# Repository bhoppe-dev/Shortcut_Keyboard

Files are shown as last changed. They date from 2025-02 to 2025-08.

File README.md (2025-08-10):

# Shortcut Keyboard

A programmable macro keyboard project featuring 8 customizable keys and a rotary encoder for volume control. Built with an RP2040 microcontroller and Cherry MX switches.

<p align="center">
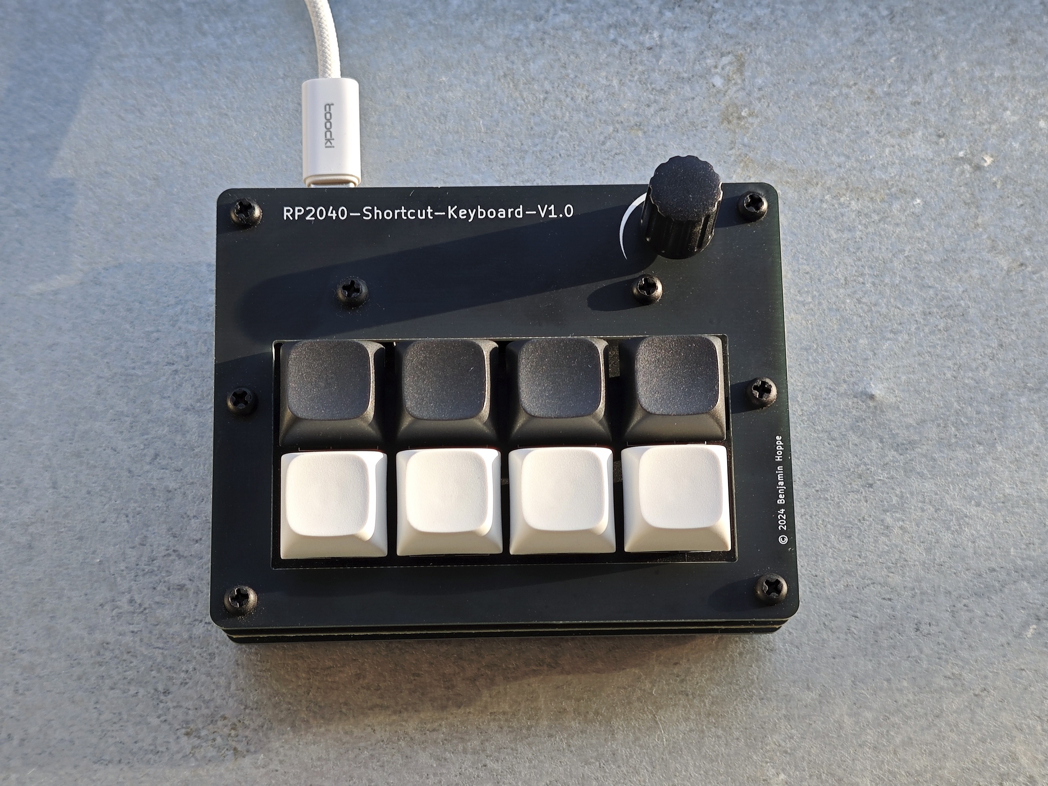
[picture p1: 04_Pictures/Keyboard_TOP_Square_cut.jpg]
  
  <br>
  <em>Shortcut Keyboard PCB</em>
</p>

## Features

- 8 programmable macro keys with Cherry MX switches (Blue or Brown)
- Rotary encoder with push button for volume control/mute
- USB-C connectivity
- RP2040 microcontroller
- CircuitPython firmware
- Windows compatibility
- Up to 3 different profiles for key configurations
- No additional drivers required

## Specifications

| Parameter | Value |
|---|---|
| Input Voltage | 4.75-5.25V (USB) |
| Operating Current | ~50mA |
| Operating Temperature | 0-85°C |
| PCB Dimensions | 100 x 79 mm |
| Switches | Cherry MX Blue/Brown |
| Communication | USB HID |
| MCU | RP2040 |
| Firmware | CircuitPython |

## Hardware

The keyboard consists of three PCBs:
1. Main board with RP2040 and components
2. Top plate
3. Bottom plate

### Key Switch Options

| Feature | MX Blue | MX Brown |
|---|---|---|
| Actuation Force | 60 cN | 55 cN |
| Pre-travel | 2.2 mm | 2.0 mm |
| Total Travel | 4.0 mm | 4.0 mm |
| Characteristics | Tactile & Clicky | Tactile |
| Sound | Audible click | Silent |

## Software

> The source code is available on GitHub at [https://github.com/bhoppe-dev/ShortcutKeyboardApp](https://github.com/bhoppe-dev/ShortcutKeyboardApp).
> 
The software suite includes:
- Windows configuration application
- Three customizable profiles
- File/folder/application launch capabilities
- URL opening support
- System tray integration
- Dark mode support

<p align="center">
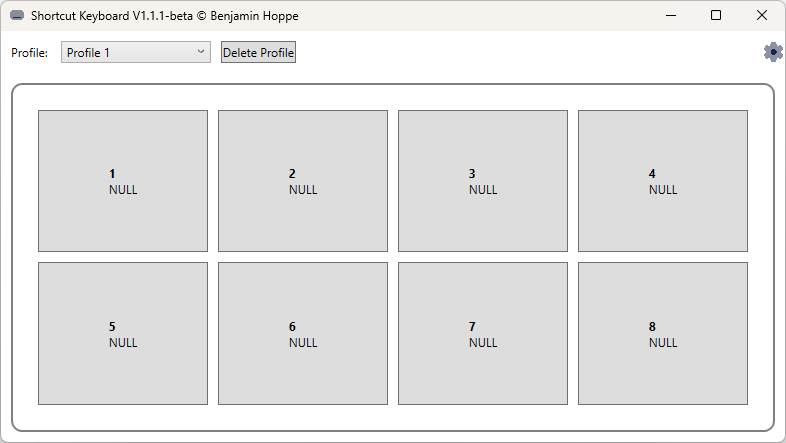
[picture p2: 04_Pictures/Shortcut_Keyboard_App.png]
  
  <br>
  <em>Main Window</em>
</p>

<p align="center">
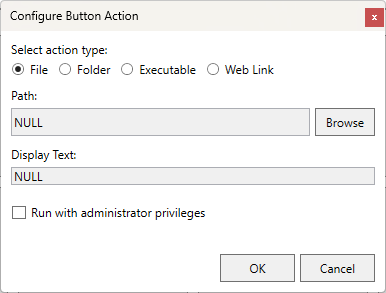
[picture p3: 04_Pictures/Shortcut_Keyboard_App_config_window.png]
  
  <br>
  <em>Configuration Window</em>
</p>

## Firmware

The keyboard runs CircuitPython firmware with the following features:
- USB HID implementation
- Key debouncing
- Rotary encoder support
- Volume control integration
- Multiple profile support

## License

This project is licensed under the BSD 2-Clause License - see the LICENSE file for details.

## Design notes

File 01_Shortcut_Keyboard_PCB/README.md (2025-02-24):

# PCB Documentation

KiCad project files for the Shortcut-Keyboard PCB based on RP2040.

## RP2040 Interface Block Diagram
Interface overview of the used RP2040 microcontroller pins and buses:

<p align="center">
  
  <br>
  <em>RP2040 Microcontroller Interface</em>
</p>

## Directory Structure

### Folders
- `01_Schematic/` - Schematic exports and documentation
- `02_BOM/` - Bill of Materials and part lists
- `03_STEP/` - 3D models and mechanical files

### KiCad Files
- `shortcut_keyboard.kicad_pro` - Project file
- `shortcut_keyboard.kicad_sch` - Main schematic
- `shortcut_keyboard.kicad_pcb` - PCB layout
- `MCU.kicad_sch` - MCU specific schematic
- `Connector.kicad_sch` - Connector specific schematic
- `Revision_History.kicad_sch` - Version tracking

## Layer Stackup
This PCB uses a SIG/GND/VCC/SIG stackup instead of the more conventional SIG/GND/GND/SIG configuration. This decision was based on several design considerations:

1. **Design Optimization:** The chosen stackup provides an optimal balance between routing efficiency and performance for this specific application.

2. **Signal Requirements Analysis:** After analyzing the signal integrity requirements for the RP2040-based keyboard, I determined that the modest-speed signals don't demand the theoretical advantages of dual ground planes.

3. **Power Distribution:** The dedicated VCC plane on L3 provides sufficient power distribution for all components while simplifying the overall routing strategy.

4. **Manufacturing Considerations:** The SIG/GND/VCC/SIG configuration maintains the same manufacturing complexity while offering adequate electrical performance for this application.

5. **Application-Specific Design:** For this particular keyboard application, the SIG/GND/VCC/SIG arrangement meets all functional requirements while enabling a more streamlined development process.

## Specifications
- Size: 100 x 79 mm
- Layers: 4 layer, 1.6mm FR4
- Version: V1.00.01 (2025-02-02)
- KiCad Version: 8.0.7

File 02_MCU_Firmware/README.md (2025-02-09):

# Shortcut Keyboard Firmware

CircuitPython firmware for the Shortcut Keyboard project, implementing an 8-key programmable macro keyboard with volume control functionality.

## Overview

This firmware powers the Shortcut Keyboard using CircuitPython and the RP2040 microcontroller. It provides a implementation of programmable shortcut keys and volume control through a rotary encoder.

## Features

- 8 programmable macro keys using SHIFT+ALT+CTRL + letter combinations
- Volume control via rotary encoder with mute functionality
- Built-in debouncing for reliable key detection
- Error indication via onboard LED
- Comprehensive error logging
- USB HID compliance for wide compatibility

## Technical Specifications

- **MCU**: RP2040
- **Version**: V1.1.1-beta
- **Language**: CircuitPython
- **Encoder Step**: 2 steps per click

## Pin Configuration

### Macro Keys
- GP0-GP7: Programmable shortcut buttons

### Rotary Encoder
- GP19: Encoder Pin A
- GP18: Encoder Pin B
- GP20: Encoder Push Button (Mute)

### Status Indication
- GP25: Onboard LED for error indication

## Default Key Mappings

Each button is configured to send a combination of SHIFT+ALT+CTRL + letter:

| Pin  | Key Combination |
|---|---|
| GP0  | SHIFT + ALT + CTRL + A |
| GP1  | SHIFT + ALT + CTRL + B |
| GP2  | SHIFT + ALT + CTRL + C |
| GP3  | SHIFT + ALT + CTRL + D |
| GP4  | SHIFT + ALT + CTRL + E |
| GP5  | SHIFT + ALT + CTRL + F |
| GP6  | SHIFT + ALT + CTRL + G |
| GP7  | SHIFT + ALT + CTRL + H |

## Dependencies

- `board`
- `digitalio`
- `rotaryio`
- `usb_hid`
- `adafruit_hid.keyboard`
- `adafruit_hid.keycode`
- `adafruit_hid.consumer_control`
- `adafruit_hid.consumer_control_code`

## Installation

1. Install CircuitPython on your RP2040 board
2. Copy the firmware file to the CircuitPython drive
3. Ensure all required libraries are in the `lib` folder

## Error Handling

The firmware includes comprehensive error handling with visual feedback:
- Errors are indicated via the onboard LED (GP25)
- Error messages are printed to serial console
- LED duration for errors: 2 seconds

## Functions

### Core Functions
- `setup_error_led()`: Initializes the onboard LED for error indication
- `setup_buttons()`: Configures the 8 programmable buttons with pull-up resistors
- `setup_rotary_encoder()`: Initializes the volume control encoder
- `setup_usb_devices()`: Sets up USB HID interfaces

### Polling Functions
- `poll_buttons()`: Monitors button states and sends key combinations
- `poll_rotary_encoder()`: Handles volume control and mute functionality

### Utility Functions
- `log_error()`: Logs errors with LED indication
- `log_info()`: Logs informational messages

## License

This firmware is part of the Shortcut Keyboard project and is licensed under the BSD 2-Clause License.

## Author

Benjamin Hoppe

---

For more information about the complete Shortcut Keyboard project, please refer to the main project README.

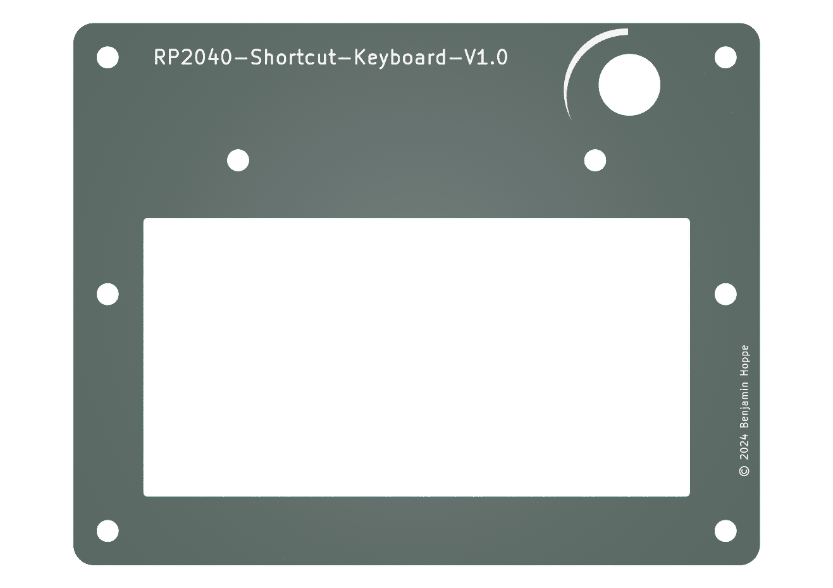
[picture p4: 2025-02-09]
03_Shortcut_Keyboard_Case/Shortcut_Keyboard_Case_TOP/02_Pictures/Shortcut_Keyboard_Case_TOP.png

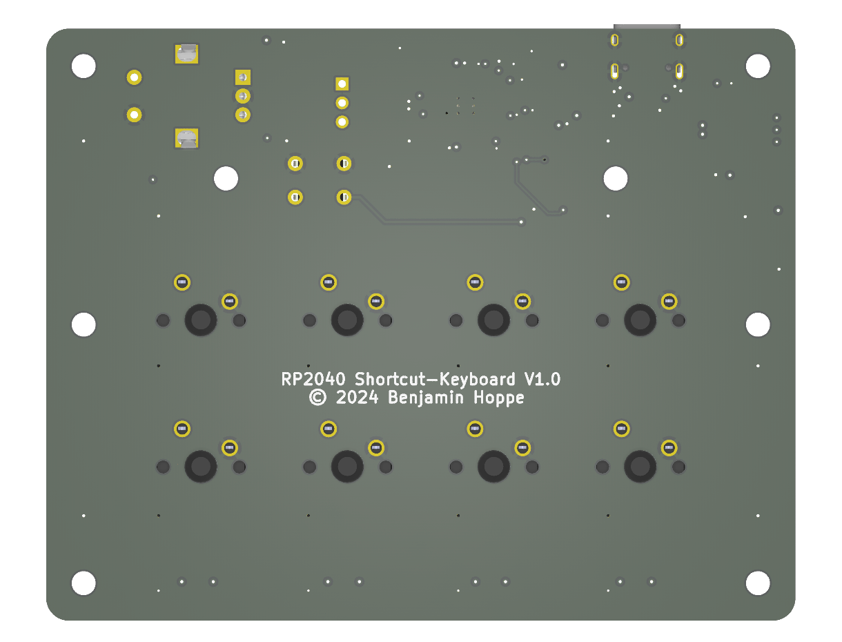
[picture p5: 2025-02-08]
04_Pictures/shortcut_keyboard_bot.png

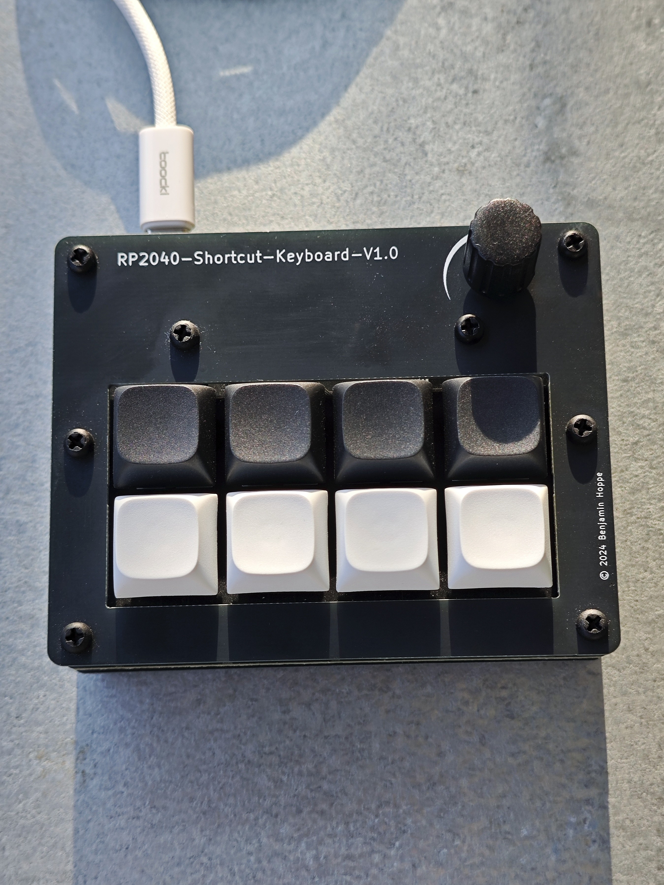
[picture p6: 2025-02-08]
04_Pictures/Keyboard_Top_Portrait_cut.jpg

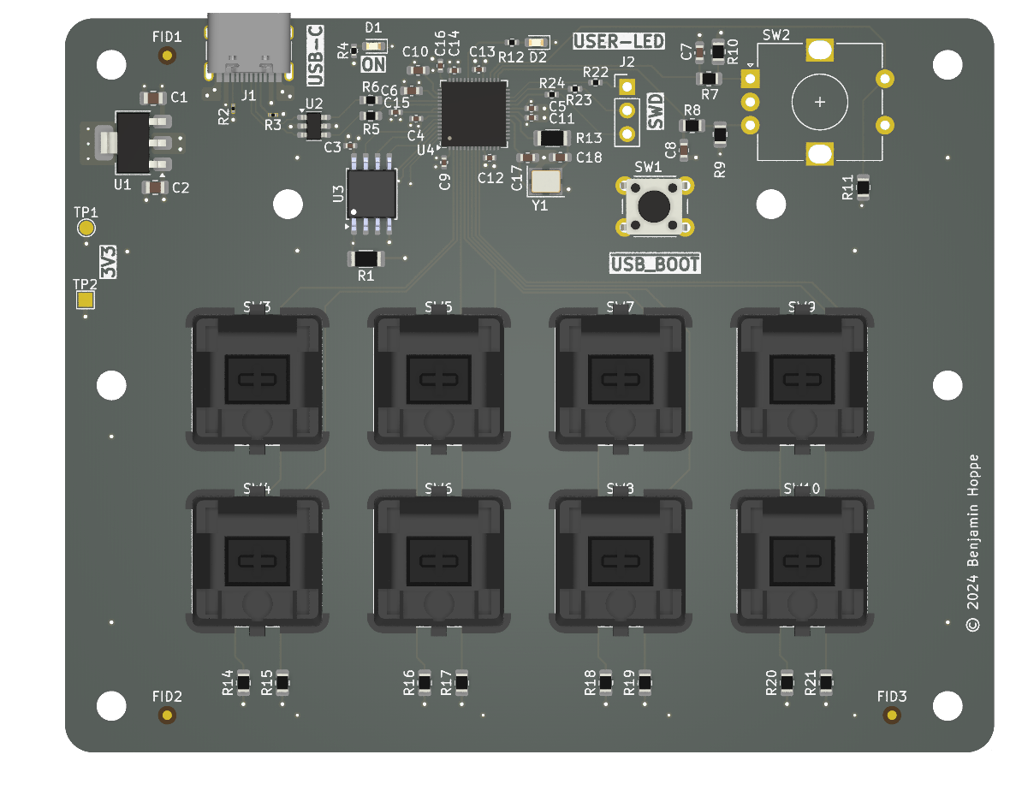
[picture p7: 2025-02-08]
04_Pictures/shortcut_keyboard_top.png

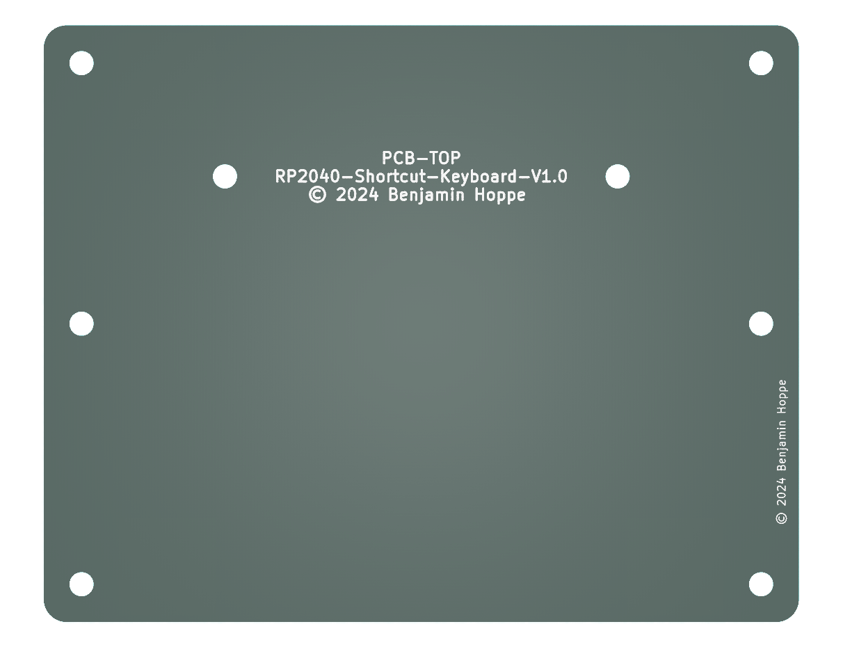
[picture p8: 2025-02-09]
03_Shortcut_Keyboard_Case/Shortcut_Keyboard_Case_BOT/02_Pictures/Shortcut_Keyboard_Case_BOT.png

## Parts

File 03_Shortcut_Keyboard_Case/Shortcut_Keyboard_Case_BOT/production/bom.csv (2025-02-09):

Designator | Footprint | Quantity | Value | LCSC Part #
H1, H2, H3, H4, H5, H6, H7, H8 | MountingHole_3.2mm_M3 | 8 | MountingHole

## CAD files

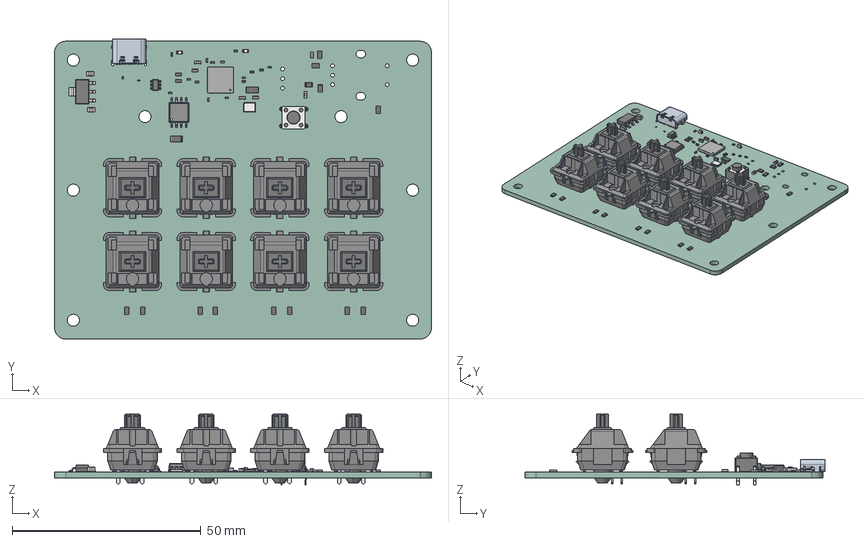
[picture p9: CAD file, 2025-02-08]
01_Shortcut_Keyboard_PCB/03_STEP/shortcut_keyboard.step
100.0 x 79.6 x 18.7 mm
C_0603_1608Metric x 6
C_0402_1005Metric x 10
MX1A-11NN x 8
R_1206_3216Metric x 2
R_0805_2012Metric x 13
R_0402_1005Metric x 5
C_0805_2012Metric x 2
R_0603_1608Metric x 2
LED_0603_1608Metric x 2
R_0201_0603Metric x 2
SOT_223
SW_PUSH_6mm_h5mm
SOT_23_6
W25Q32JWSSIQ
QFN_56_1EP_7x7mm_P04mm_EP32x32mm
GSB1C41X111DS1HR
Crystal_SMD_3225-4Pin_3.2x2.5mm
_autosave-shortcut_keyboard_PCB

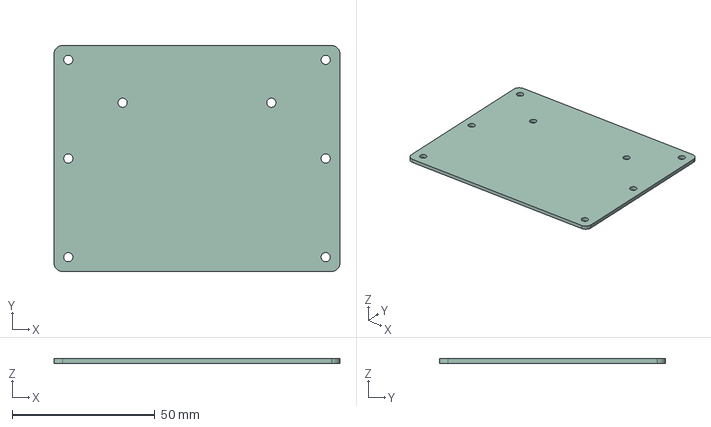
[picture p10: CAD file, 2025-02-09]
03_Shortcut_Keyboard_Case/Shortcut_Keyboard_Case_BOT/01_STEP/Shortcut_Keyboard_Case_BOT.step
100.0 x 79.0 x 1.60 mm

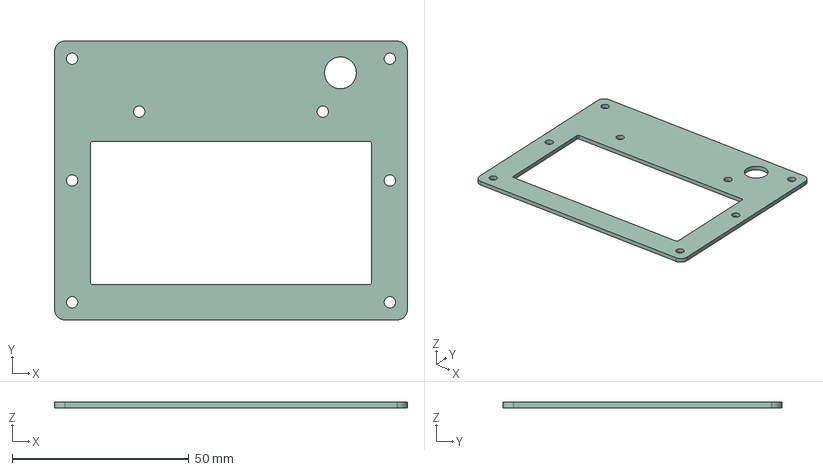
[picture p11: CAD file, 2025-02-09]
03_Shortcut_Keyboard_Case/Shortcut_Keyboard_Case_TOP/01_STEP/Shortcut_Keyboard_Case_TOP.step
100.0 x 79.0 x 1.60 mm

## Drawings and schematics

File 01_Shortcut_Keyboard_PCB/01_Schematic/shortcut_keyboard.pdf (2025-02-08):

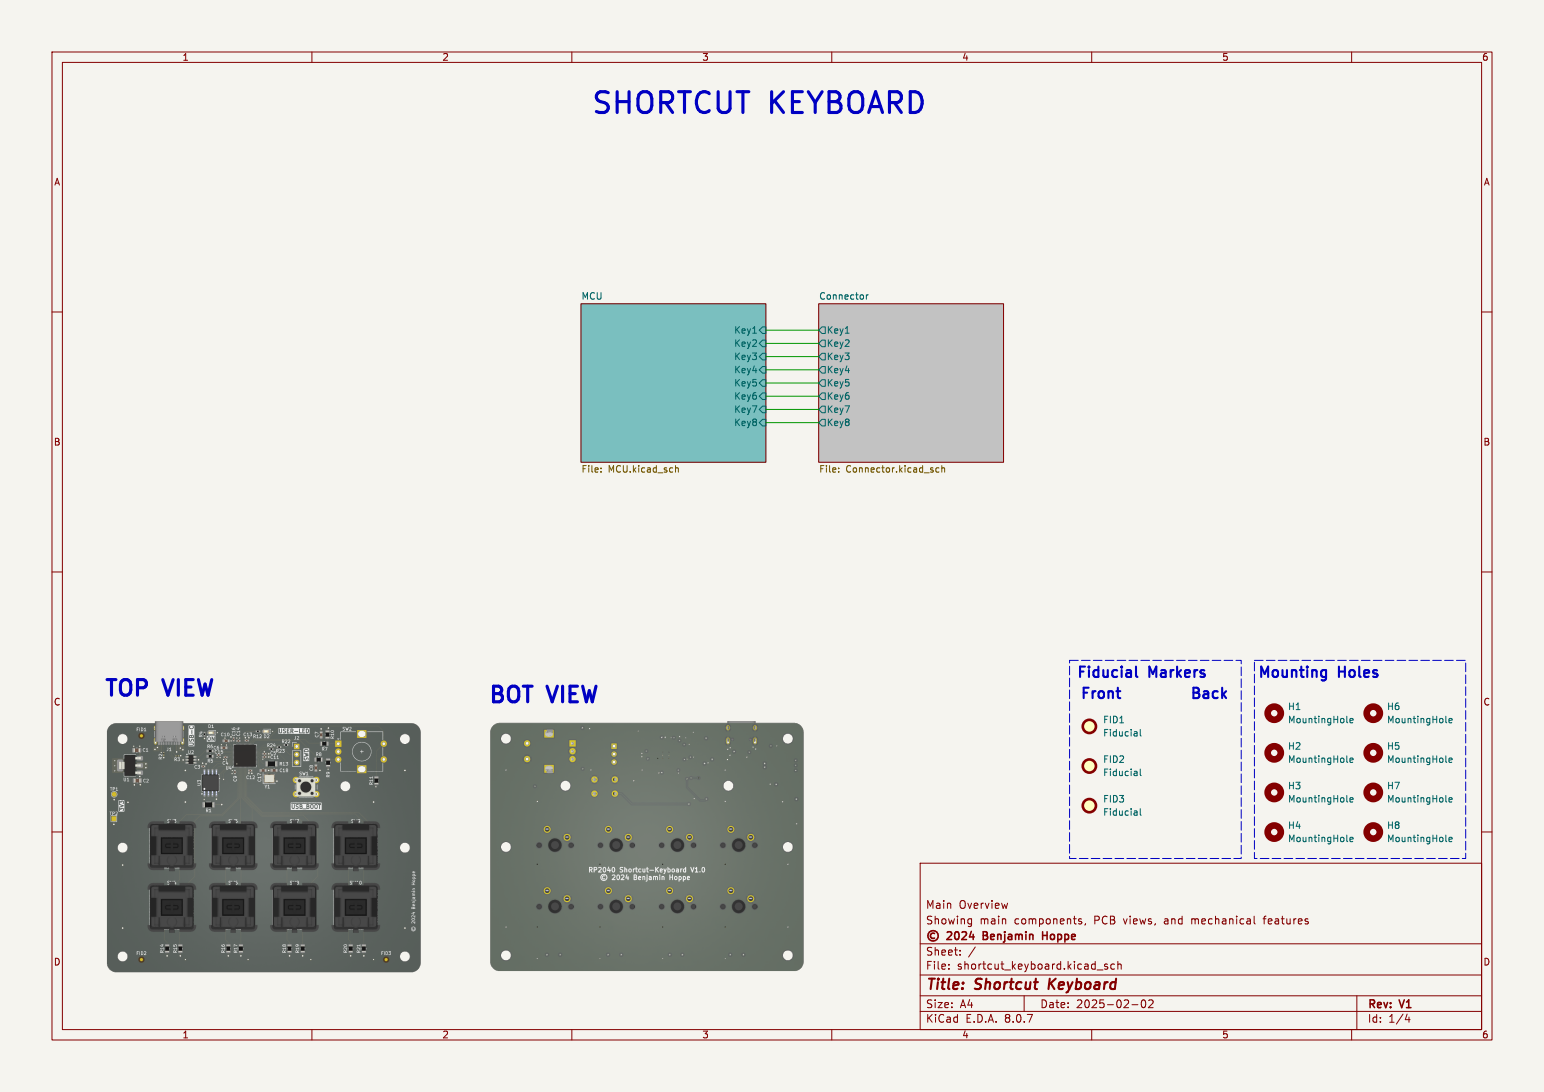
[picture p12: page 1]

Id: 1/4 Title: Shortcut Keyboard

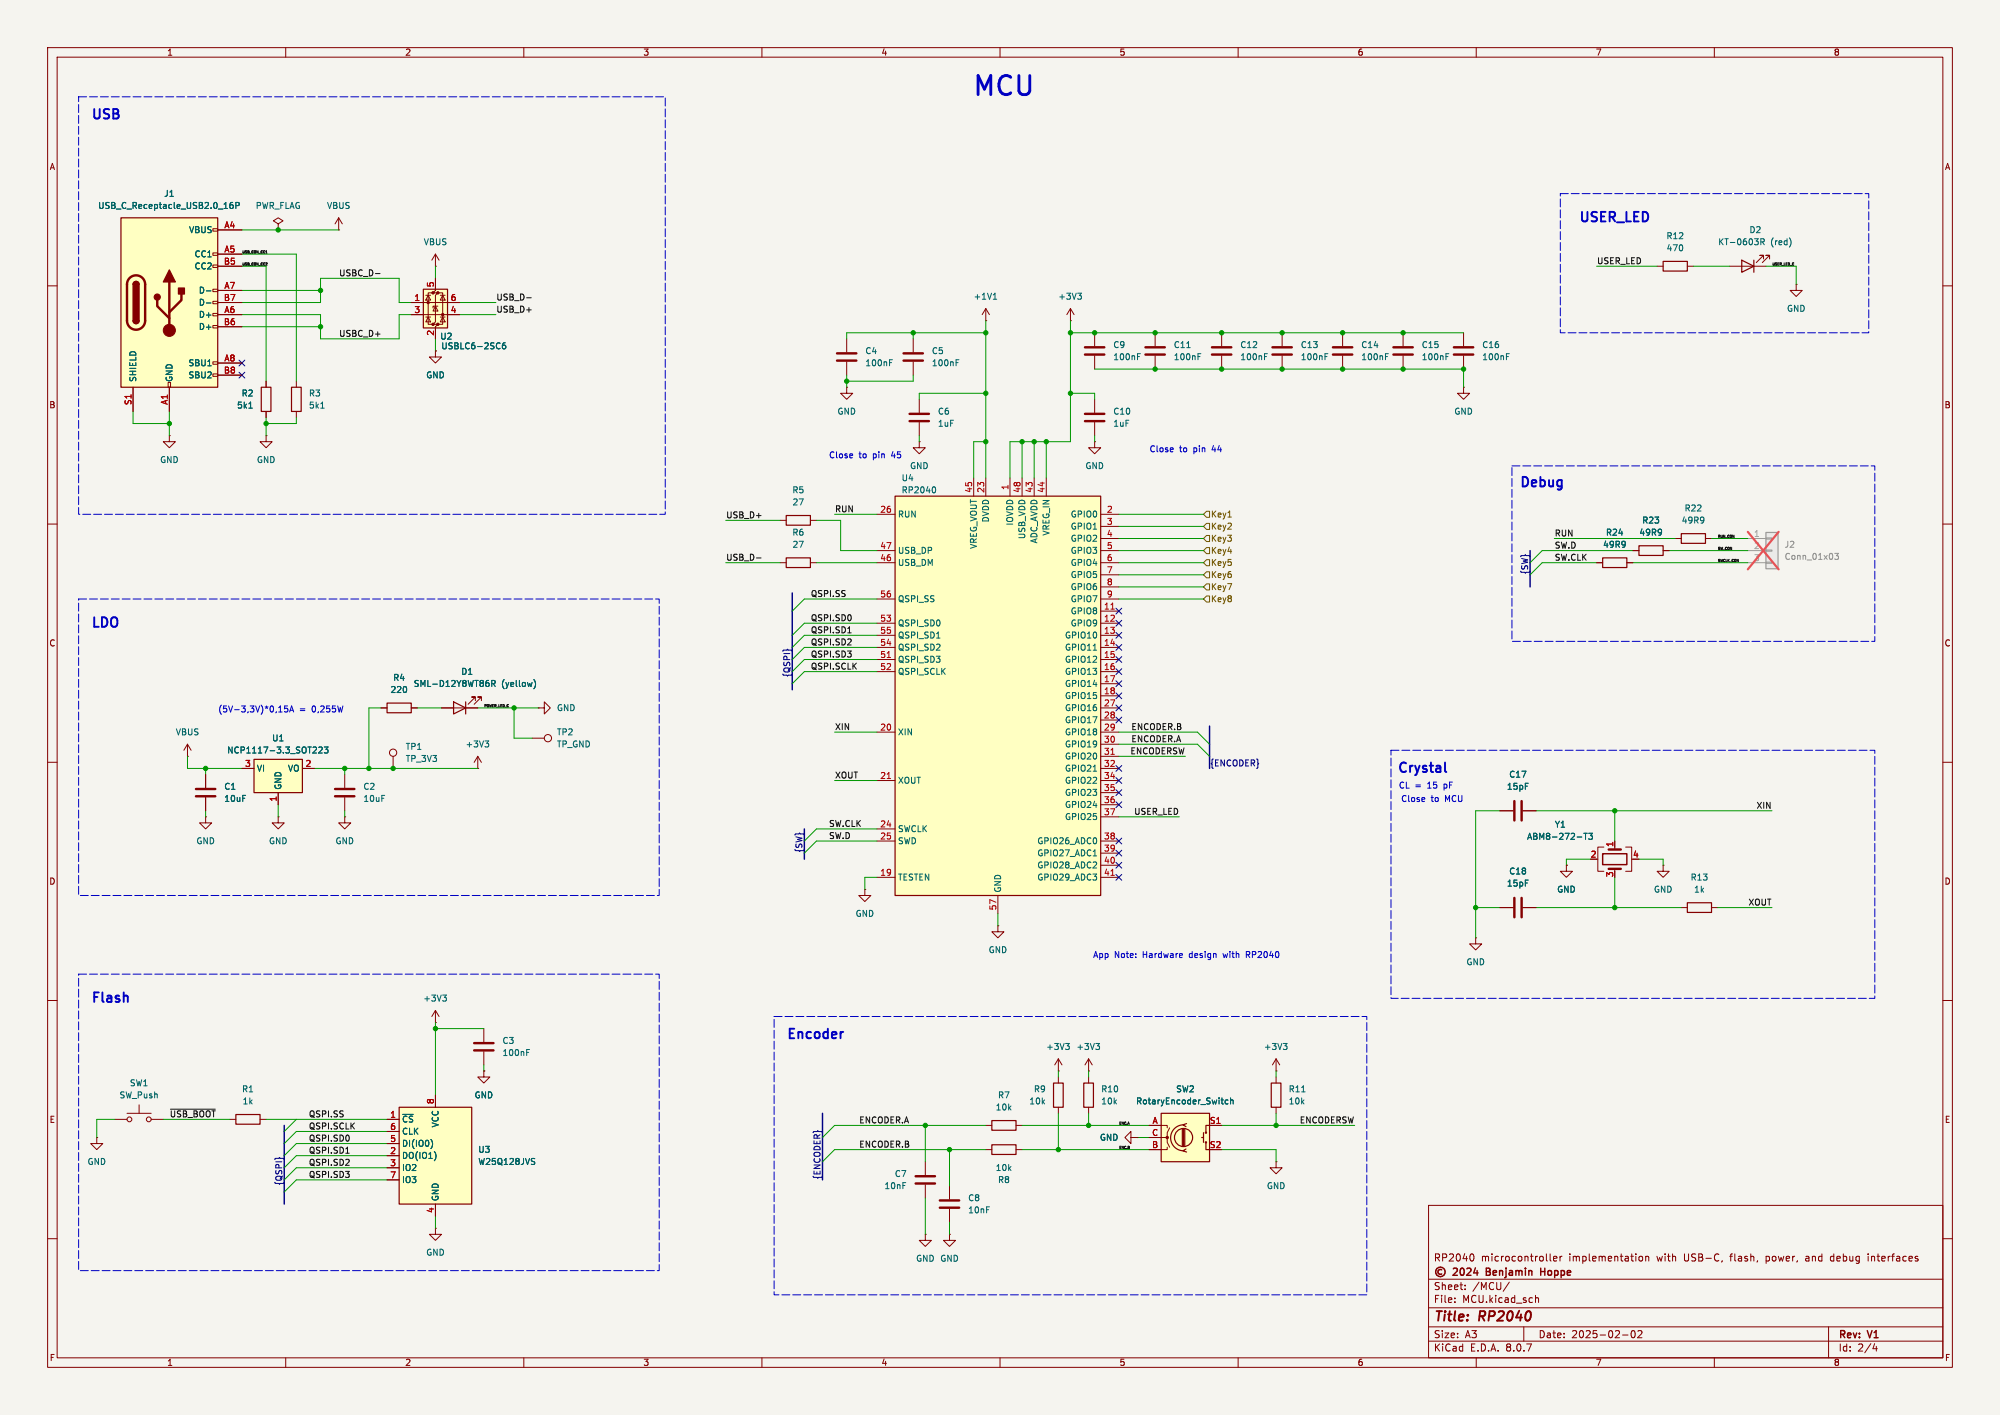
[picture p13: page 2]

App Note: Hardware design with RP2040 (https://datasheets.raspberrypi.com/rp2040/hardware-design-with-rp2040.pdf) MCU

1 GPIO8 11 GPIO9 12 GPIO10 13 GPIO11 14 GPIO12 15 GPIO13 16 GPIO14 17 GPIO15 18 TESTEN 19 GPIO0 2 XIN 20 XOUT 21 DVDD 23 SWCLK 24 SWD 25 RUN 26 GPIO16 27 GPIO17 28 GPIO18 29 GPIO1 3 GPIO19 30 GPIO20 31 GPIO21 32 GPIO22 34 GPIO23 35 GPIO24 36 GPIO25 37 GPIO26_ADC0 38 GPIO27_ADC1 39 GPIO2 4 GPIO28_ADC2 40 GPIO29_ADC3 41 ADC_AVDD 43 VREG_IN 44 VREG_VOUT 45 USB_DM 46 USB_DP 47 USB_VDD 48 GPIO3 5 QSPI_SD3 51 QSPI_SCLK 52 QSPI_SD0 53 QSPI_SD2 54 QSPI_SD1 55 QSPI_SS 56 GND 57 GPIO4 6 GPIO5 7 GPIO6 8 GPIO7 9 U4 RP2040

XOUT QSPI.SD2 QSPI.SD0 LDO

{ENCODER} XOUT XIN QSPI.SS QSPI.SCLK

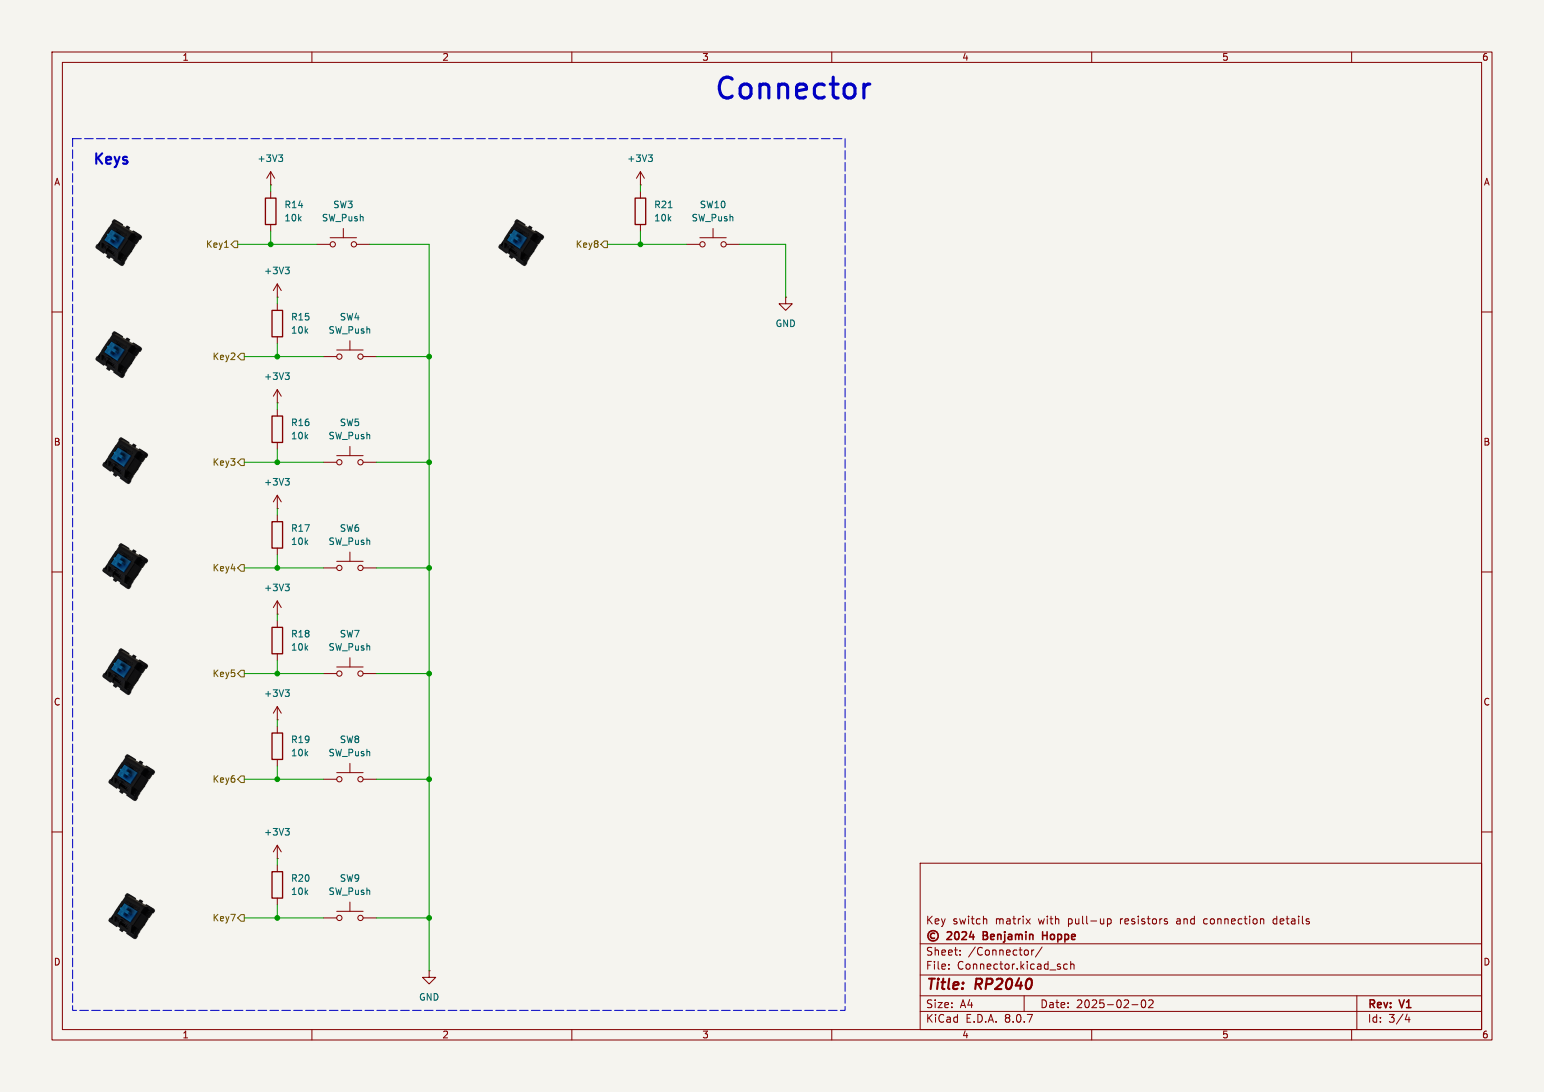
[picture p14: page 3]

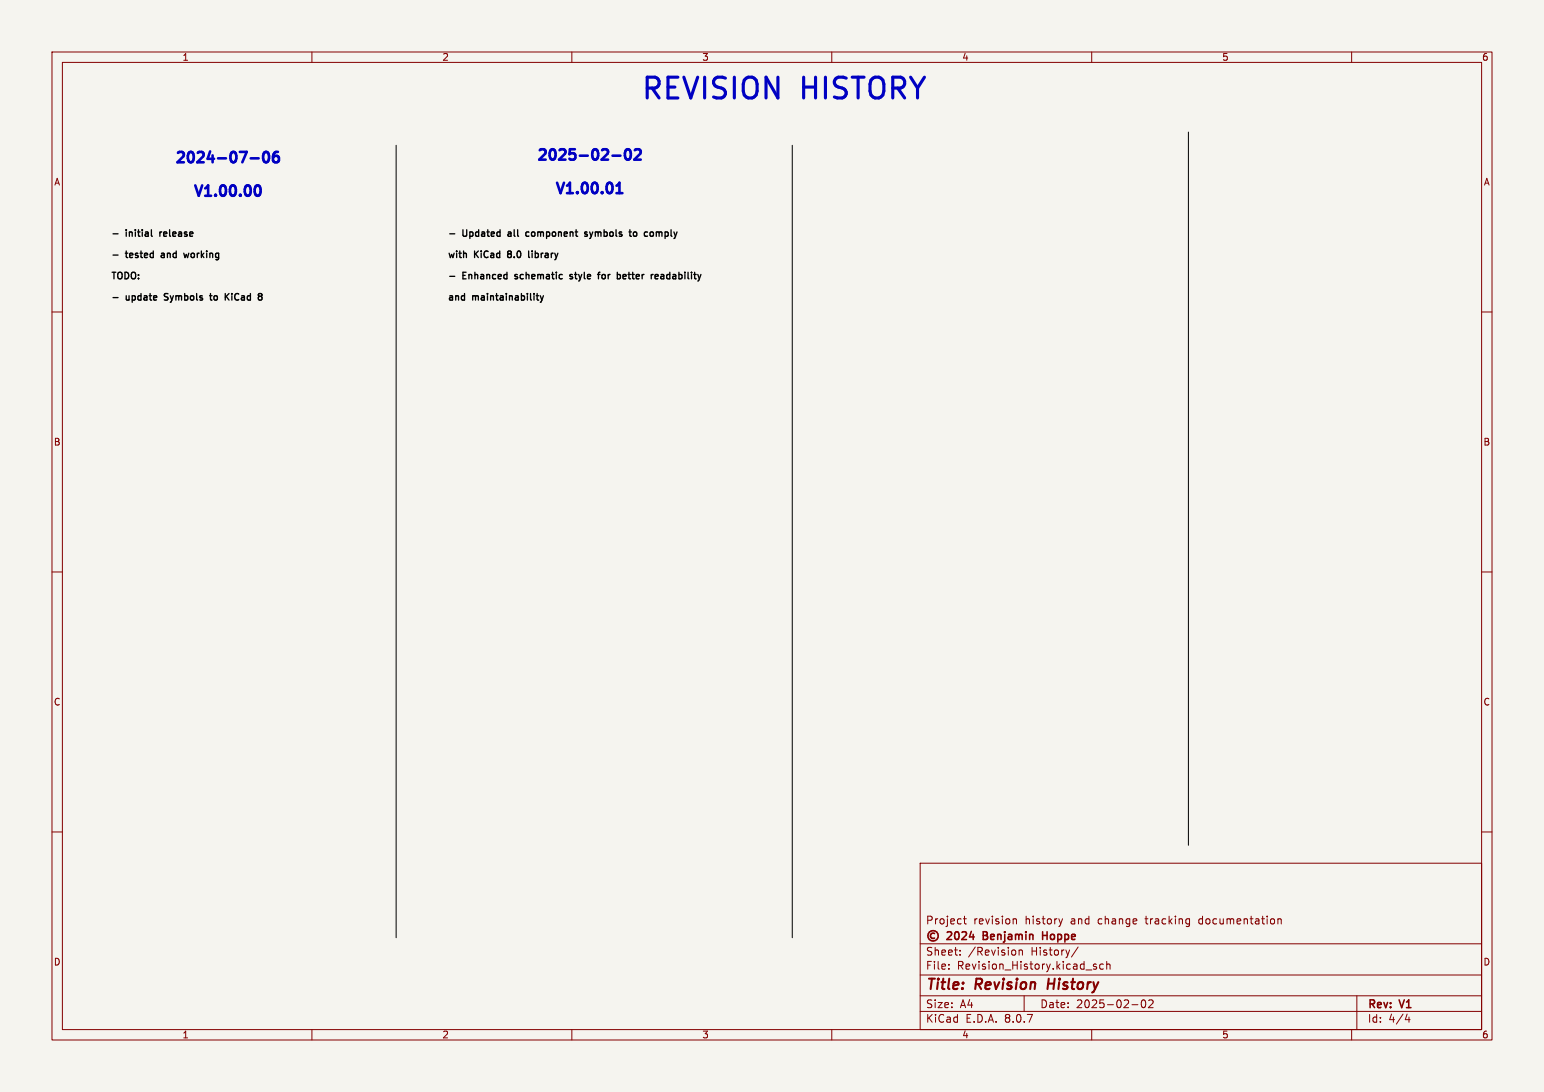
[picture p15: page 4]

- Updated all component symbols to comply with KiCad 8.0 library

- Enhanced schematic style for better readability

- update Symbols to KiCad 8

Id: 4/4 Title: Revision History

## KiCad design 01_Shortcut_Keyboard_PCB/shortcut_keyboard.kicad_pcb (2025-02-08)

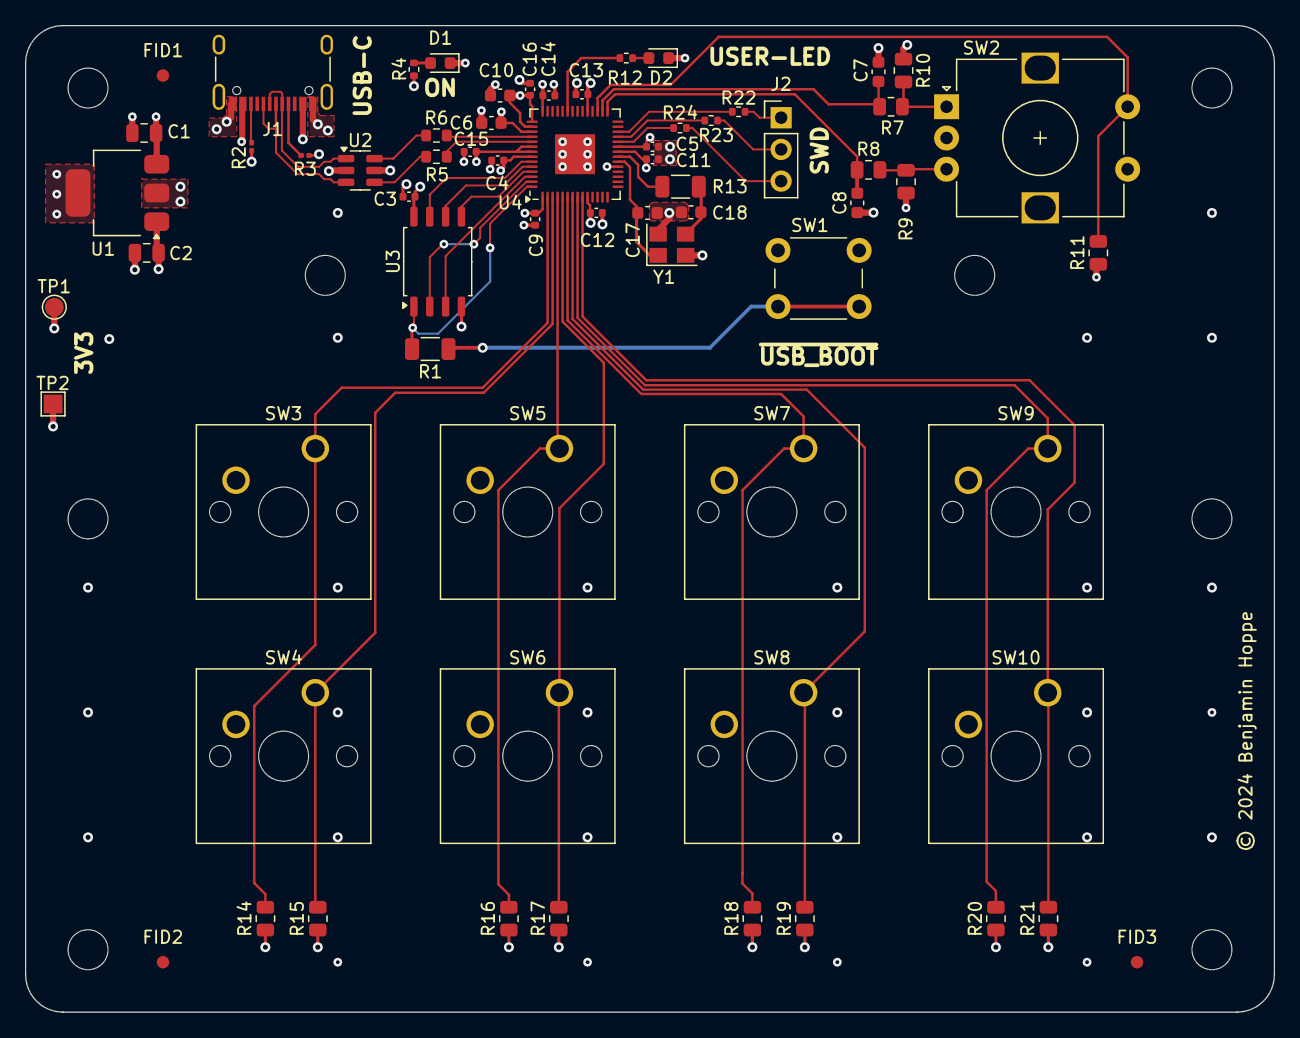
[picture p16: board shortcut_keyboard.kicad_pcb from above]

Board: 4 copper layers, 100.0 x 79.0 mm, 74 parts (0 on the bottom side), 44 nets.

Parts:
C1, C2: 10uF; C_0805_2012Metric
C3, C4, C5, C9, C11, C12, C13, C14, C15, C16: 100nF; C_0402_1005Metric
C6, C10: 1uF; C_0603_1608Metric
C7, C8: 10nF; C_0603_1608Metric
C17, C18: 15pF; C_0603_1608Metric
D1: SML-D12Y8WT86R (yellow); LED_0603_1608Metric
D2: KT-0603R (red); LED_0603_1608Metric
FID1, FID2, FID3: Fiducial; Fiducial_1mm_Mask2mm
H1, H2, H3, H4, H5, H6, H7, H8: MountingHole; MountingHole_3.2mm_M3
J1: USB_C_Receptacle_USB2.0_16P; USB_C_Receptacle_XKB_U262-16XN-4BVC11
J2: Conn_01x03; PinHeader_1x03_P2.54mm_Vertical
R1, R13: 1k; R_1206_3216Metric
R2, R3: 5k1; R_0201_0603Metric
R4: 220; R_0402_1005Metric
R5, R6: 27; R_0603_1608Metric
R7, R8, R9, R10, R11, R14, R15, R16, R17, R18, R19, R20, R21: 10k; R_0805_2012Metric
R12: 470; R_0402_1005Metric
R22, R23, R24: 49R9; R_0402_1005Metric
SW1: SW_Push; SW_PUSH_6mm_H5mm
SW2: RotaryEncoder_Switch; RotaryEncoder_Alps_EC12E-Switch_Vertical_H20mm
SW3, SW4, SW5, SW6, SW7, SW8, SW9, SW10: SW_Push; SW_Cherry_MX_1.00u_PCB
TP1: TP_3V3; TestPoint_Pad_D1.5mm
TP2: TP_GND; TestPoint_Pad_1.5x1.5mm
U1: NCP1117-3.3_SOT223; SOT-223-3_TabPin2
U2: USBLC6-2SC6; SOT-23-6
U3: W25Q128JVS; SOIC-8_5.23x5.23mm_P1.27mm
U4: RP2040; QFN-56-1EP_7x7mm_P0.4mm_EP3.2x3.2mm
Y1: ABM8-272-T3; Crystal_SMD_3225-4Pin_3.2x2.5mm

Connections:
+1V1: C4.1, C5.1, C6.1, U4.23 (DVDD), U4.45 (VREG_VOUT), U4.50 (DVDD)
+3V3: C2.1, C3.1, C9.1, C10.1, C11.1, C12.1, C13.1, C14.1, C15.1, C16.1, R4.1, R9.1, R10.1, R11.1, R14.1, R15.1, R16.1, R17.1, R18.1, R19.1, R20.1, R21.1, TP1.1, U1.2 (VO), U3.8 (VCC), U4.1 (IOVDD), U4.10 (IOVDD), U4.22 (IOVDD), U4.33 (IOVDD), U4.42 (IOVDD), U4.43 (ADC_AVDD), U4.44 (VREG_IN), U4.48 (USB_VDD), U4.49 (IOVDD)
/Connector/Key1: R14.2, SW3.1, U4.2 (GPIO0)
/Connector/Key2: R15.2, SW4.1, U4.3 (GPIO1)
/Connector/Key3: R16.2, SW5.1, U4.4 (GPIO2)
/Connector/Key4: R17.2, SW6.1, U4.5 (GPIO3)
/Connector/Key5: R18.2, SW7.1, U4.6 (GPIO4)
/Connector/Key6: R19.2, SW8.1, U4.7 (GPIO5)
/Connector/Key7: R20.2, SW9.1, U4.8 (GPIO6)
/Connector/Key8: R21.2, SW10.1, U4.9 (GPIO7)
/MCU/ENC.A: R7.2, R10.2, SW2.A
/MCU/ENC.B: R8.2, R9.2, SW2.B
/MCU/ENCODER.A: C7.1, R7.1, U4.30 (GPIO19)
/MCU/ENCODER.B: C8.1, R8.1, U4.29 (GPIO18)
/MCU/ENCODERSW: R11.2, SW2.S1, U4.31 (GPIO20)
/MCU/QSPI.SCLK: U3.6 (CLK), U4.52 (QSPI_SCLK)
/MCU/QSPI.SD0: U3.5 (DI(IO0)), U4.53 (QSPI_SD0)
/MCU/QSPI.SD1: U3.2 (DO(IO1)), U4.55 (QSPI_SD1)
/MCU/QSPI.SD2: U3.3 (IO2), U4.54 (QSPI_SD2)
/MCU/QSPI.SD3: U3.7 (IO3), U4.51 (QSPI_SD3)
/MCU/QSPI.SS: R1.2, U3.1 (~CS), U4.56 (QSPI_SS)
/MCU/RUN: R22.1, U4.26 (RUN)
/MCU/RUN_CON: J2.1, R22.2
/MCU/SW.CLK: R24.1, U4.24 (SWCLK)
/MCU/SW.D: R23.1, U4.25 (SWD)
/MCU/SWCLK_CON: J2.3, R24.2
/MCU/SW_CON: J2.2, R23.2
/MCU/USBC_D+: J1.A6 (D+), J1.B6 (D+), U2.3 (I/O2)
/MCU/USBC_D-: J1.A7 (D-), J1.B7 (D-), U2.1 (I/O1)
/MCU/USB_CON_CC1: J1.A5 (CC1), R3.1
/MCU/USB_CON_CC2: J1.B5 (CC2), R2.1
/MCU/USB_D+: R5.1, U2.4 (I/O2)
/MCU/USB_D-: R6.1, U2.6 (I/O1)
/MCU/USER_LED: R12.1, U4.37 (GPIO25)
/MCU/XIN: C17.1, U4.20 (XIN), Y1.1
/MCU/XOUT: R13.2, U4.21 (XOUT)
/MCU/~USB_BOOT: R1.1, SW1.2
GND: C1.2, C2.2, C3.2, C4.2, C5.2, C6.2, C7.2, C8.2, C9.2, C10.2, C11.2, C12.2, C13.2, C14.2, C15.2, C16.2, C17.2, C18.2, D1.1 (K), D2.1 (K), J1.A1 (GND), J1.A12 (GND), J1.B1 (GND), J1.B12 (GND), J1.S1 (SHIELD), R2.2, R3.2, SW1.1, SW2.C, SW2.S2, SW3.2, SW4.2, SW5.2, SW6.2, SW7.2, SW8.2, SW9.2, SW10.2, TP2.1, U1.1 (GND), U2.2 (GND), U3.4 (GND), U4.19 (TESTEN), U4.57 (GND), Y1.2, Y1.4
unnamed: C18.1, R13.1, Y1.3
unnamed: D1.2 (A), R4.2
unnamed: D2.2 (A), R12.2
unnamed: R6.2, U4.46 (USB_DM)
unnamed: R5.2, U4.47 (USB_DP)
VBUS: C1.1, J1.A4 (VBUS), J1.A9 (VBUS), J1.B4 (VBUS), J1.B9 (VBUS), U1.3 (VI), U2.5 (VBUS)

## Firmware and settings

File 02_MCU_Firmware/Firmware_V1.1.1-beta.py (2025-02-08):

"""
Project_Name: Shortcut_Keyboard
Author: Benjamin Hoppe
Date: 24.11.2024
Version: V1.1.1-beta

Description:
============
This Python script is designed to create a shortcut keyboard using a RP2040 microcontroller.
It uses the Adafruit HID library to send media control commands over USB.

Key Features:
- 8 programmable shortcut buttons (GP0-GP7)
- Volume control via rotary encoder
- Error indication via onboard LED
- Debouncing for reliable button presses
"""

import time
import board
import digitalio
import rotaryio
import usb_hid
from adafruit_hid.keyboard import Keyboard
from adafruit_hid.keycode import Keycode
from adafruit_hid.consumer_control import ConsumerControl
from adafruit_hid.consumer_control_code import ConsumerControlCode

# Software version
SOFTWARE_VERSION = "1.1.1-beta"

# Constants
BUTTON_DELAY = 0.2
POLLING_INTERVAL = 0.05  # Time between each main loop iteration
ENCODER_STEP = 2  # How many volume steps per encoder click
ERROR_LED_DURATION = 2
DEBOUNCE_DELAY = 0.3  # Minimum time between button presses in seconds

# Button configuration
# Each button sends SHIFT+ALT+CTRL + Letter combination
BUTTONS = [
    {"pin": board.GP0, "combo": [Keycode.LEFT_SHIFT, Keycode.LEFT_ALT, Keycode.LEFT_CONTROL, Keycode.A]},
    {"pin": board.GP1, "combo": [Keycode.LEFT_SHIFT, Keycode.LEFT_ALT, Keycode.LEFT_CONTROL, Keycode.B]},
    {"pin": board.GP2, "combo": [Keycode.LEFT_SHIFT, Keycode.LEFT_ALT, Keycode.LEFT_CONTROL, Keycode.C]},
    {"pin": board.GP3, "combo": [Keycode.LEFT_SHIFT, Keycode.LEFT_ALT, Keycode.LEFT_CONTROL, Keycode.D]},
    {"pin": board.GP4, "combo": [Keycode.LEFT_SHIFT, Keycode.LEFT_ALT, Keycode.LEFT_CONTROL, Keycode.E]},
    {"pin": board.GP5, "combo": [Keycode.LEFT_SHIFT, Keycode.LEFT_ALT, Keycode.LEFT_CONTROL, Keycode.F]},
    {"pin": board.GP6, "combo": [Keycode.LEFT_SHIFT, Keycode.LEFT_ALT, Keycode.LEFT_CONTROL, Keycode.G]},
    {"pin": board.GP7, "combo": [Keycode.LEFT_SHIFT, Keycode.LEFT_ALT, Keycode.LEFT_CONTROL, Keycode.H]},
]

# Rotary Encoder configuration - Used for volume control
ROTARY_PIN_A = board.GP19
ROTARY_PIN_B = board.GP18
ROTARY_BUTTON_PIN = board.GP20  # Press to mute

# LED configuration - Uses onboard LED for error indication
ERROR_LED_PIN = board.GP25  # Onboard LED of the Raspberry Pi Pico

# Global variables
error_led = None
button_last_press_times = {}  # Stores the last press time for each button
button_states = {}  # Stores the current state of each button

def setup_error_led():
    global error_led
    error_led = digitalio.DigitalInOut(ERROR_LED_PIN)
    error_led.direction = digitalio.Direction.OUTPUT

def log_error(message):
    print(f"ERROR: {message}")
    if error_led:
        error_led.value = True
        time.sleep(ERROR_LED_DURATION)
        error_led.value = False

def log_info(message):
    print(f"INFO: {message}")

def setup_buttons():
    """Initialize all shortcut buttons with pull-up resistors enabled"""
    try:
        buttons = []
        for i, button_config in enumerate(BUTTONS):
            btn = digitalio.DigitalInOut(button_config["pin"])
            btn.direction = digitalio.Direction.INPUT
            btn.pull = digitalio.Pull.UP  # Button pressed = LOW, not pressed = HIGH
            buttons.append({
                "button": btn,
                "combo": button_config["combo"],
                "id": i  # Use an index as unique identifier
            })
            # Initialize the button states and last press times
            button_states[i] = True  # True = not pressed
            button_last_press_times[i] = 0
        return buttons
    except Exception as e:
        log_error(f"Error setting up buttons: {e}")
        return None

def setup_rotary_encoder():
    """Initialize the rotary encoder for volume control"""
    try:
        encoder = rotaryio.IncrementalEncoder(ROTARY_PIN_A, ROTARY_PIN_B)
        button = digitalio.DigitalInOut(ROTARY_BUTTON_PIN)
        button.direction = digitalio.Direction.INPUT
        button.pull = digitalio.Pull.UP
        return encoder, button
    except Exception as e:
        log_error(f"Error setting up rotary encoder: {e}")
        return None, None

def setup_usb_devices():
    """Initialize USB HID devices for keyboard and media control"""
    try:
        keyboard = Keyboard(usb_hid.devices)
        consumer_control = ConsumerControl(usb_hid.devices)
        return keyboard, consumer_control
    except Exception as e:
        log_error(f"Error setting up USB devices: {e}")
        return None, None

def poll_buttons(buttons, keyboard):
    """Check button states and send key combinations if pressed"""
    try:
        current_time = time.monotonic()

        for button in buttons:
            button_id = button["id"]
            current_state = button["button"].value

            # Check if the button state has changed
            if current_state != button_states[button_id]:
                # If button is pressed (remember, pulled up, so 0 = pressed)
                if current_state == 0:
                    # Check if enough time has passed since last press (debouncing)
                    if current_time - button_last_press_times[button_id] >= DEBOUNCE_DELAY:
                        # Send the keypress combination (e.g., SHIFT+ALT+CTRL+A)
                        keyboard.press(*button["combo"])
                        keyboard.release_all()
                        # Update the last press time
                        button_last_press_times[button_id] = current_time

                # Update the stored state
                button_states[button_id] = current_state

    except Exception as e:
        log_error(f"Error polling buttons: {e}")

def poll_rotary_encoder(encoder, button, consumer_control, last_position, last_button_state):
    """Handle volume control via rotary encoder"""
    try:
        current_position = encoder.position
        if current_position != last_position:
            # Rotate right = volume up, rotate left = volume down
            if current_position > last_position:
                for _ in range(ENCODER_STEP):
                    consumer_control.send(ConsumerControlCode.VOLUME_INCREMENT)
            else:
                for _ in range(ENCODER_STEP):
                    consumer_control.send(ConsumerControlCode.VOLUME_DECREMENT)
            time.sleep(0.01)

        # Check for encoder button press (mute function)
        current_button_state = button.value
        if current_button_state == 0 and last_button_state == 1:
            consumer_control.send(ConsumerControlCode.MUTE)
            time.sleep(BUTTON_DELAY)

        return current_position, current_button_state
    except Exception as e:
        log_error(f"Error polling rotary encoder: {e}")
        return last_position, last_button_state

def main():
    log_info(f'Shortcut-Keyboard by Benjamin Hoppe - Version: {SOFTWARE_VERSION}')
    setup_error_led()
    buttons = setup_buttons()
    encoder, encoder_button = setup_rotary_encoder()
    keyboard, consumer_control = setup_usb_devices()

    if buttons is None or encoder is None or encoder_button is None or keyboard is None or consumer_control is None:
        log_error("Error setting up devices. Terminating program.")
        return

    last_encoder_position = encoder.position
    last_button_state = encoder_button.value

    # Main program loop
    while True:
        poll_buttons(buttons, keyboard)
        last_encoder_position, last_button_state = poll_rotary_encoder(
            encoder, encoder_button, consumer_control, last_encoder_position, last_button_state
        )
        time.sleep(POLLING_INTERVAL)

if __name__ == "__main__":
    try:
        main()
    except KeyboardInterrupt:
        log_info("Keyboard interrupt. Terminating program.")
    except Exception as e:
        log_error(f"Error: {e}")

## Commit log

2025-02-08 docs: Add initial README
    - Add comprehensive project description and features
    - Include hardware specifications and PCB details
    - Note status of upcoming C# configuration software
2025-02-08 docs: Update keyboard PCB image in README
    Replace Keyboard_Top_Portrait_cut.jpg with Keyboard_TOP_Square_cut.jpg
2025-02-09 Add enclosure design files
    [Shortcut_Keyboard_Case_BOT.kicad_pcb, Shortcut_Keyboard_Case_BOT.kicad_sch, Shortcut_Keyboard_Case_BOT.step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]
2025-02-13 docs(pcb): add README with RP2040 interface block diagram
    Add PCB folder documentation with focus on RP2040 pin assignments and bus interfaces.
2025-02-13 feat(pcb): add pictures folder for documentation
2025-02-13 feat(pcb): add in pictures folder new blockdiagram
2025-02-13 docs(pcb): new SVG block diagram in README.md

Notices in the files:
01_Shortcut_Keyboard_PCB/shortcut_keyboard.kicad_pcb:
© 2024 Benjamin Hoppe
